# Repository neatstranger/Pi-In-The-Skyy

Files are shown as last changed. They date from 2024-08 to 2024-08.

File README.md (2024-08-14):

# Pi In The Skyy 

A PoE powered camera based on the Raspberry Pi Compute Module 4.
<br>

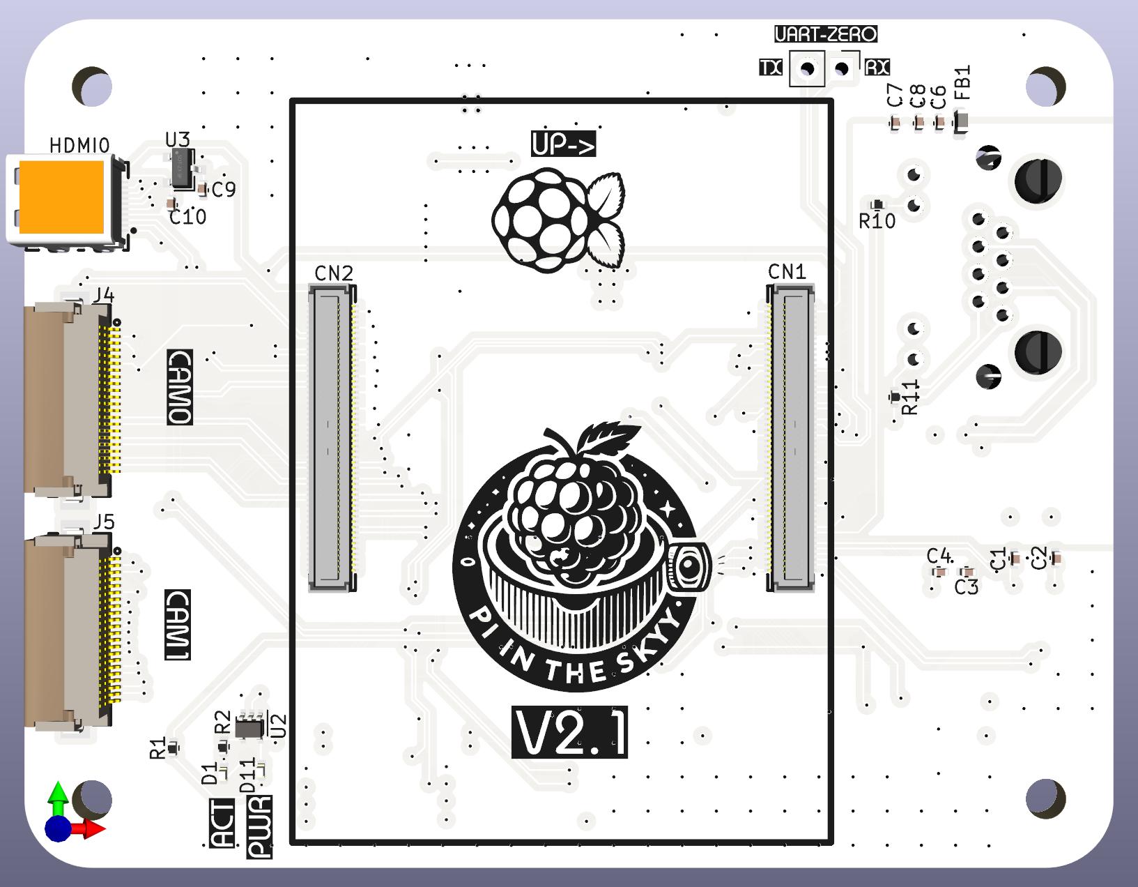
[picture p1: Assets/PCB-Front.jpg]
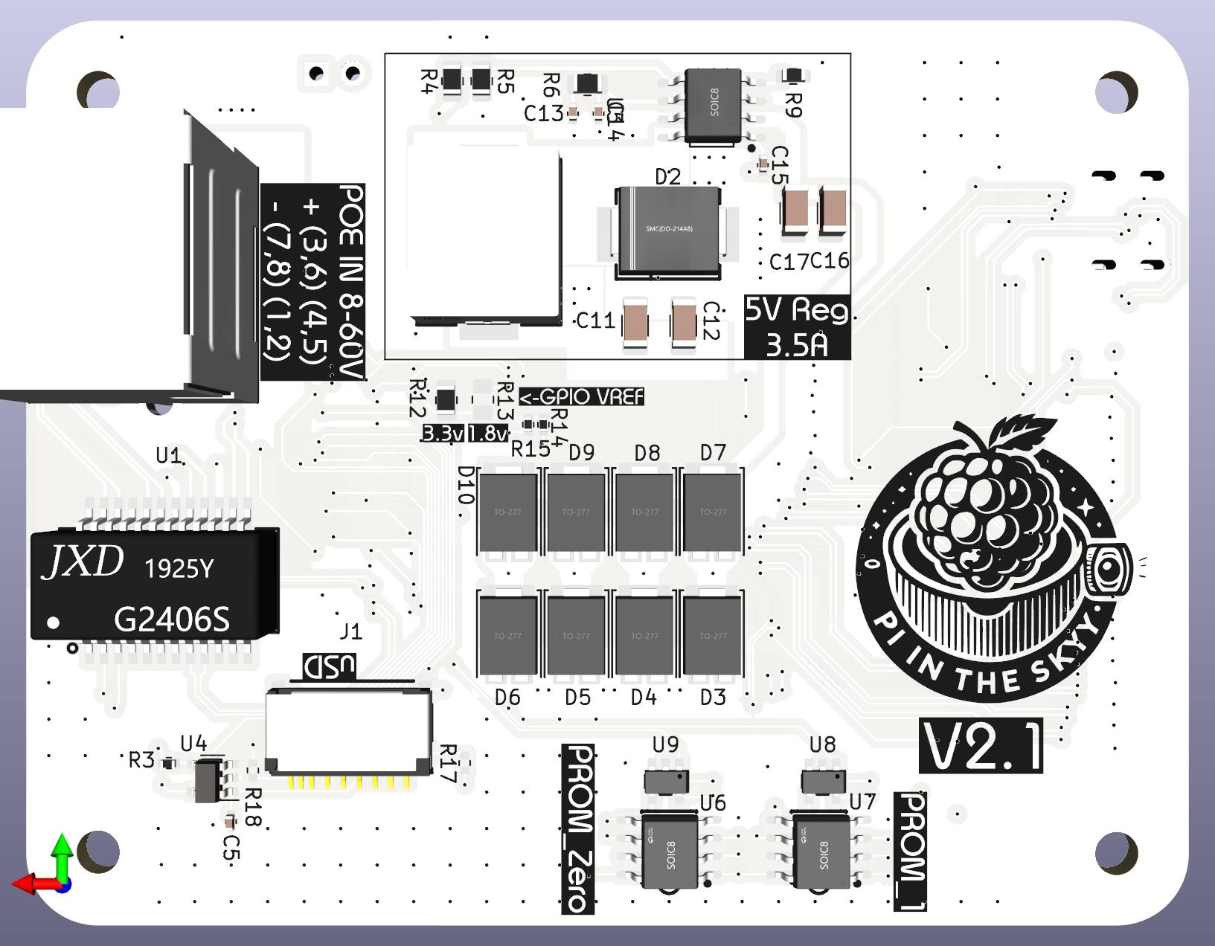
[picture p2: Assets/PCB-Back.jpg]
  

----

## Specs Overview
- Dual 22 Pin 0.5mm Pitch Camera Inputs
- Passive PoE In (8-60V)
- HDMI / UART Connectors For Troubleshooting
- Micro SD Card Slot

## Enclosure
The main body of the enclosure is designed to be 3D printed out of ASA, but PLA/PETG would work just as well. Acrylic dome found on Amazon.

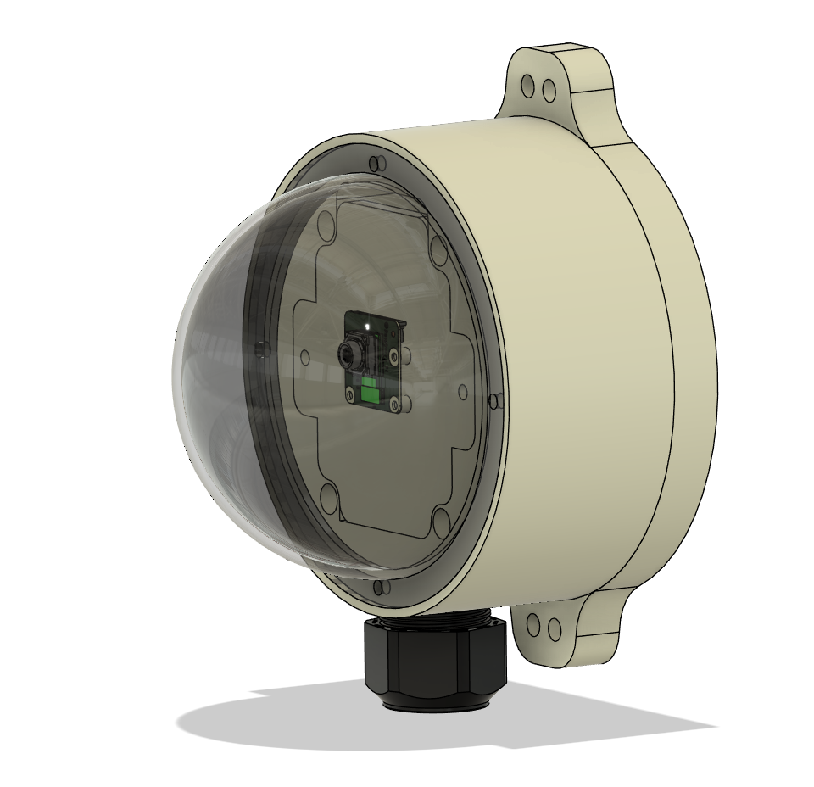
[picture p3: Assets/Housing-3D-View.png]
 

## Camera Mounting Hole Compatability
As far as I can tell, any of the first party v1, v2, and v3 cameras should work with the existing mounting plate. HQ/GS will need a new plate.

## Flexible Printed Circuit (FPC) Cable
You will need a 22 pin to 15 pin adapter cable. This is the same cable you would need to attach a first party camera to a RPi Zero, CM4IO board, or RPi5
[15 Way 1mm Spacing to 22 Way 0.5mm Spacing](https://www.pishop.us/product/camera-cable-for-raspberry-pi-5/)

## Power In
**Passive** POE IN 8-60V        Positive(3,6) (4,5)  Negative(7,8) (1,2) <br>
I have tons of passive PoE injectors from Ubiquiti equipment laying around, so I grabbed one like this:
[PoE+ Ubiquiti Injector](https://www.bhphotovideo.com/c/product/1737953-REG/ubiquiti_networks_u_poe_at_802_3at_supported_poe_injector.html/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)

All of the pairs don't have to exactly match, this one is +(4,5) , -(7,8). As long as you don't cross the expected negative and positive it should work just fine. Most PoE injectors on Amazon or otherwise will list the pinout in the description. 

Make sure you purchase one that is passive though. 
Active PoE requires components on the baord to negotiate power delivery. Which this carrier board doesn't have. We are just pulling the voltage from the center tap of the magnetics.

## Complete Part List
- [Raspberry Pi CM4](https://rpilocator.com/?cat=CM4)
- [v1, v2, v3 Camera Module](https://www.pishop.us/product/raspberry-pi-camera-module-3-wide/)
- [15 to 22 Pin Camera Cable](https://www.pishop.us/product/camera-cable-for-raspberry-pi-5/)
- Carrier Board has no source, but production files are ready to order from jlcpcb.com (Cost is ~$250 / 5 Boards)
- 3D Printed Case
- [100mm Acrylic Dome](https://www.amazon.com/dp/B07L6GLTNP?psc=1&ref=product_details)
- Various Fasteners and Heat Set Inserts. M3 for Most of Assembly, M2 For Camera Module
- [Gland For Cable Passthrough](https://www.mcmaster.com/5302N121/)

## Systemd Service for Streaming `/etc/systemd/system/camera-stream.service`
```
[Unit]
Description=open-source-nvr
Wants=network-online.target
After=network-online.target

[Service]
User=<user>
Group=<user>
Type=simple
ExecStart=/bin/sh /var/camstart.sh

[Install]
WantedBy=multi-user.target
```
^^^ Make sure to replace <user> with your login account.

## `/var/camstart.sh`
```
#!/bin/sh
rpicam-vid -t 0 --width 1920 --height 1080 --inline --nopreview --rotation 180 -o - | cvlc stream:///dev/stdin --sout '#rtp{sdp=rtsp://:8554/stream1}' :demux=h264

```

## After Creating both Files
```
sudo chmod +x /var/camstart.sh # make the service executable
sudo systemctl daemon-reload #reload the system file
sudo systemctl start camera-stream #start the camera stream
sudo systemctl enable camera-stream
```

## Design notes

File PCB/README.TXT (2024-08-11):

These files have been created in version 6 of KiCAD.

Some of the 3d models need to be downloaded form the following places and put into the CM4IO.3shapes directory some models are approximations.

https://datasheets.raspberrypi.org/cm4/CM4-step.zip
https://www.amphenol-icc.com/pci-express-1001878311200tlf.html
https://www.te.com/global-en/product-171826-4.html
https://www.molex.com/molex/products/part-detail/memory_card_socket/5033981892

The models provided in the 3dmodels directory are from various manufacturers including Diodes, Hirose, MTCONN,Toby, TRXCOM. Terms and conditions for the use of the models remain with the original manufacture.

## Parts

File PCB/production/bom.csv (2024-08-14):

Designator | Footprint | Quantity | Value | LCSC Part #
C1, C10, C2, C3, C4, C6, C7, C8, C9 | 0402 | 9 | 100n | C309458
C11, C12 | 1206 | 2 | 47u | C94034
C13 | 0402 | 1 | 6800p | C2760541
C14 | 0402 | 1 | 39p | C5186878
C15 | 0402 | 1 | 0.1u | C56392
C16, C17 | 1206 | 2 | 2.2u | C170101
C5 | 0402 | 1 | 10u | C315248
CN1, CN2 | CONN-SMD_DF40C-100DS-0.4V-51 | 2 | DF40C-100DS-0.4V(51) | C597931
D1 | 0402 | 1 | LED-RED | C434445
D10, D3, D4, D5, D6, D7, D8, D9 | TO-277A_L4.7-W6.1-LS6.6-TR | 8 | SB10100L | C113946
D11 | 0402 | 1 | LED-Green | C434446
D2 | SMC_L7.1-W6.2-LS8.1-RD | 1 | B560C-13-F | C85100
FB1 | 0603 | 1 | MPZ1608D101BTA00 | C87554
HDMI0 | HDMI-SMD_HDMI-101S | 1 | HDMI-101S | C720620
J1 | TF-SMD_TF-018 | 1 | Micro_SD_Card_Det | C961679
J4, J5 | FPC-SMD_22P-P0.50_FH12-22S-0.5SH-55 | 2 | Conn_01x22_Female | C597981
L2 | IND-SMD_L11.5-W10.0_FXL1040 | 1 | FXL1040-8R2-M | C167232
R1, R2 | 0402 | 2 | 1k | C11702
R10, R11 | 0402 | 2 | 470 | C25167
R12 | 0805 | 1 | 0R | C17477
R14, R15 | 0402 | 2 | 2.2k | C25879
R3 | 0402 | 1 | 12k | C102781
R4 | 0805 | 1 | 53.6k | C21398
R5 | 0805 | 1 | 10.2k | C217771
R6 | 0805 | 1 | 13k | C445658
R9 | 0603 | 1 | 162k | C22815
RJ2 | RJ45-TH_R-RJ45R08P-C000 | 1 | R-RJ45R08P-C000 | C386757
U1 | SMD-24_L15.1-W7.1-P1.00-LS10.0-BL | 1 | QG2439S | C3003223
U2 | SOT-353_SC-70-5 | 1 | 74LVC1G07SE-7 | C7464692
U3 | SOT-23-3_L2.9-W1.3-P1.90-LS2.4-BR | 1 | AP2331SA-7 | C500764
U4 | SOT-23-5 | 1 | RT9742GGJ5 | C250547
U5 | SOIC-8_L5.0-W4.0-P1.27-LS6.0-BL-EP2.0 | 1 | TPS54360BDDAR | C524806
U6, U7 | SOIC-8_L5.0-W4.0-P1.27-LS6.0-BL | 2 | M24C64-WMN6TP | C7999
U8, U9 | SOT-23-5_L2.9-W1.6-P0.95-LS2.8-BR | 2 | 74LVC1G125GV-TP | C3040595

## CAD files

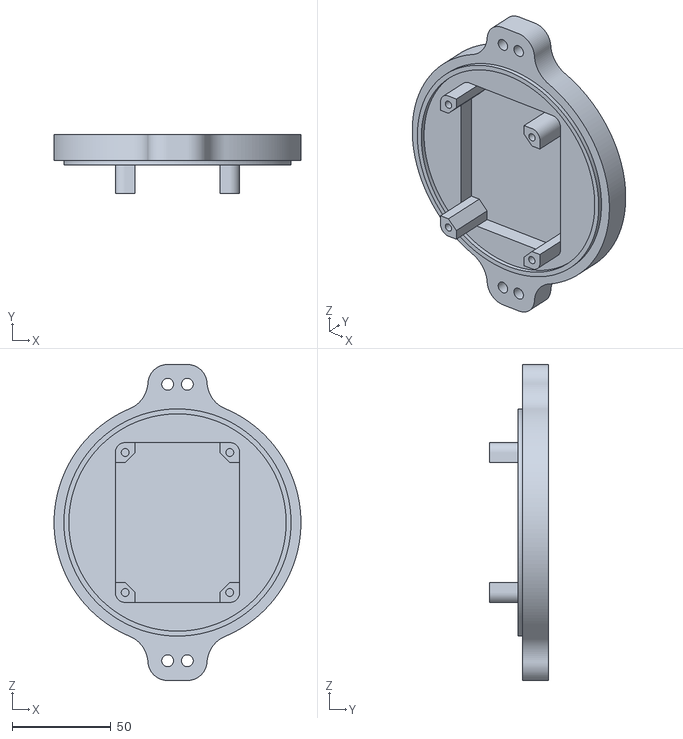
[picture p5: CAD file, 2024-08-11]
3D Files/STL/Bottom.stl
125.0 x 30.0 x 160.0

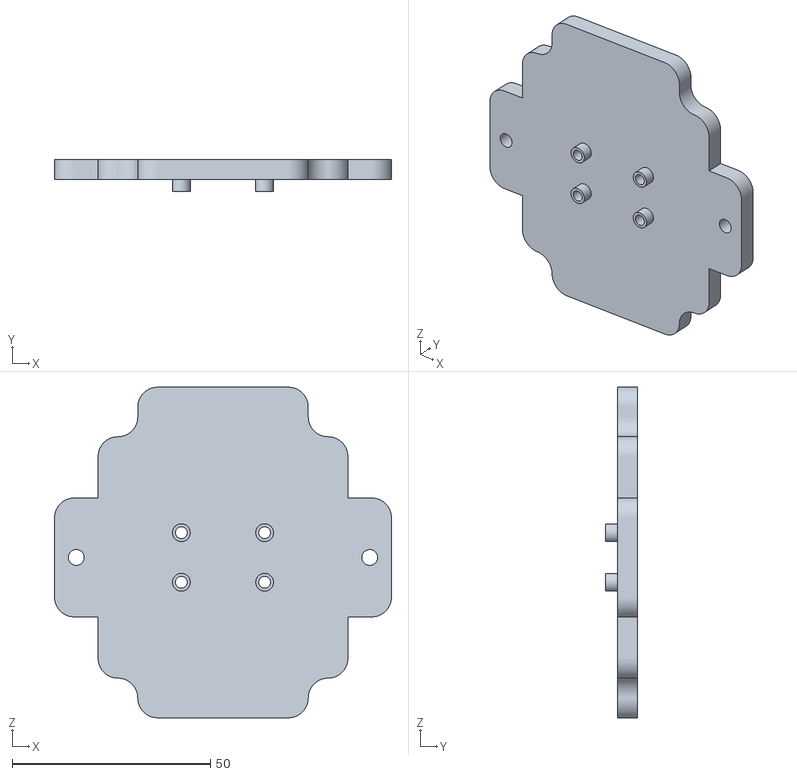
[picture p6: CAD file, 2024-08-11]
3D Files/STL/Camera Mount.stl
85.0 x 8.00 x 83.4

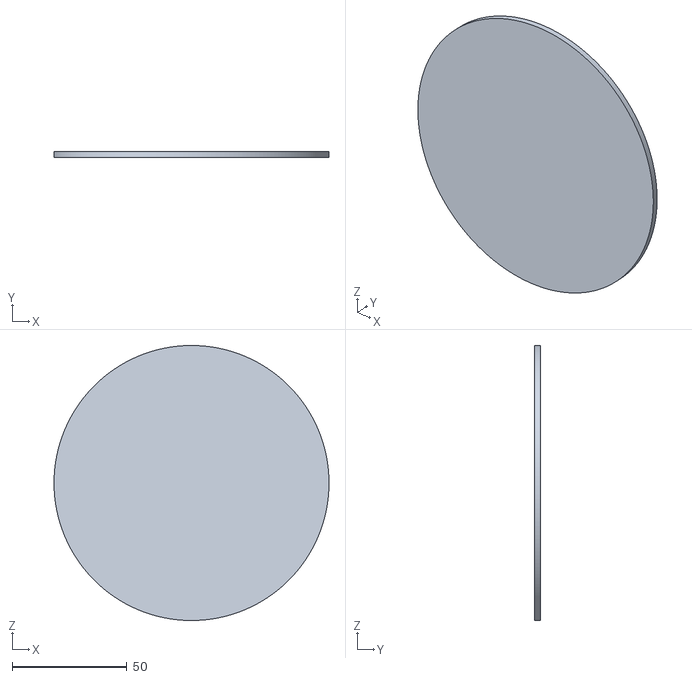
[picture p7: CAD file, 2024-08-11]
3D Files/STL/Enamel Protector.stl
120.0 x 2.50 x 120.0

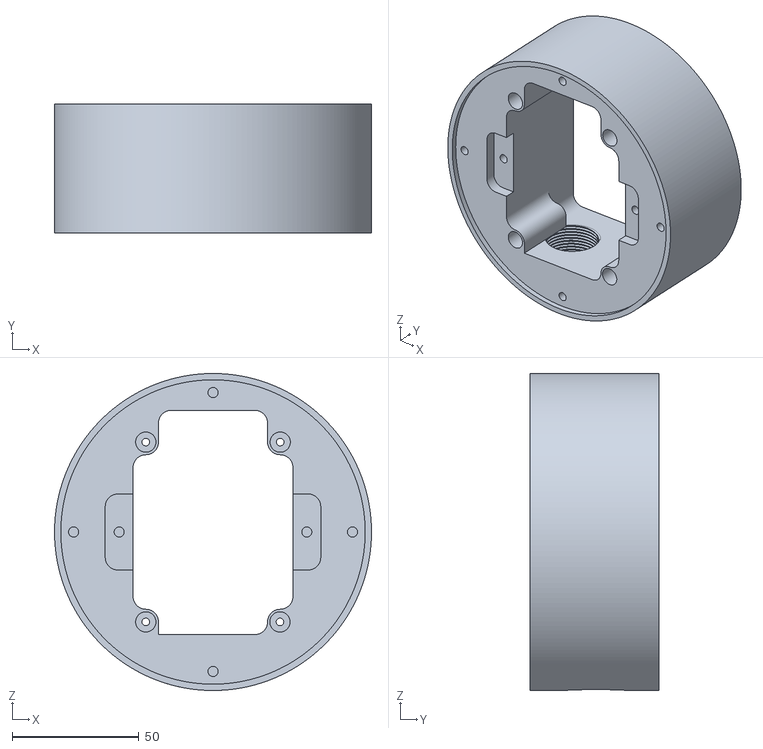
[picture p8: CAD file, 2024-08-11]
3D Files/STL/Dome Mount.stl
125.0 x 50.8 x 125.0

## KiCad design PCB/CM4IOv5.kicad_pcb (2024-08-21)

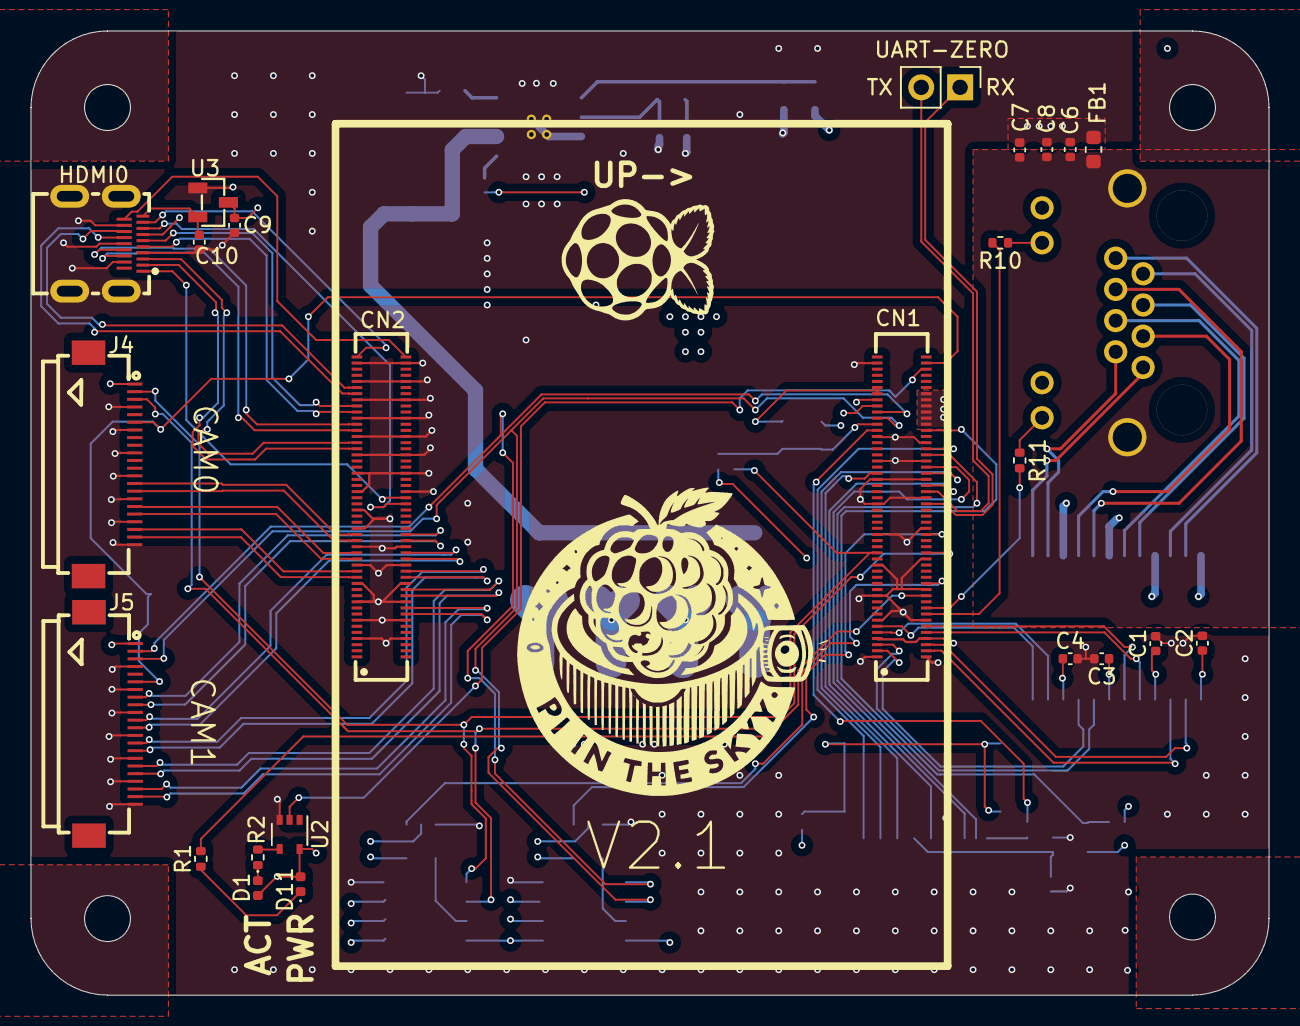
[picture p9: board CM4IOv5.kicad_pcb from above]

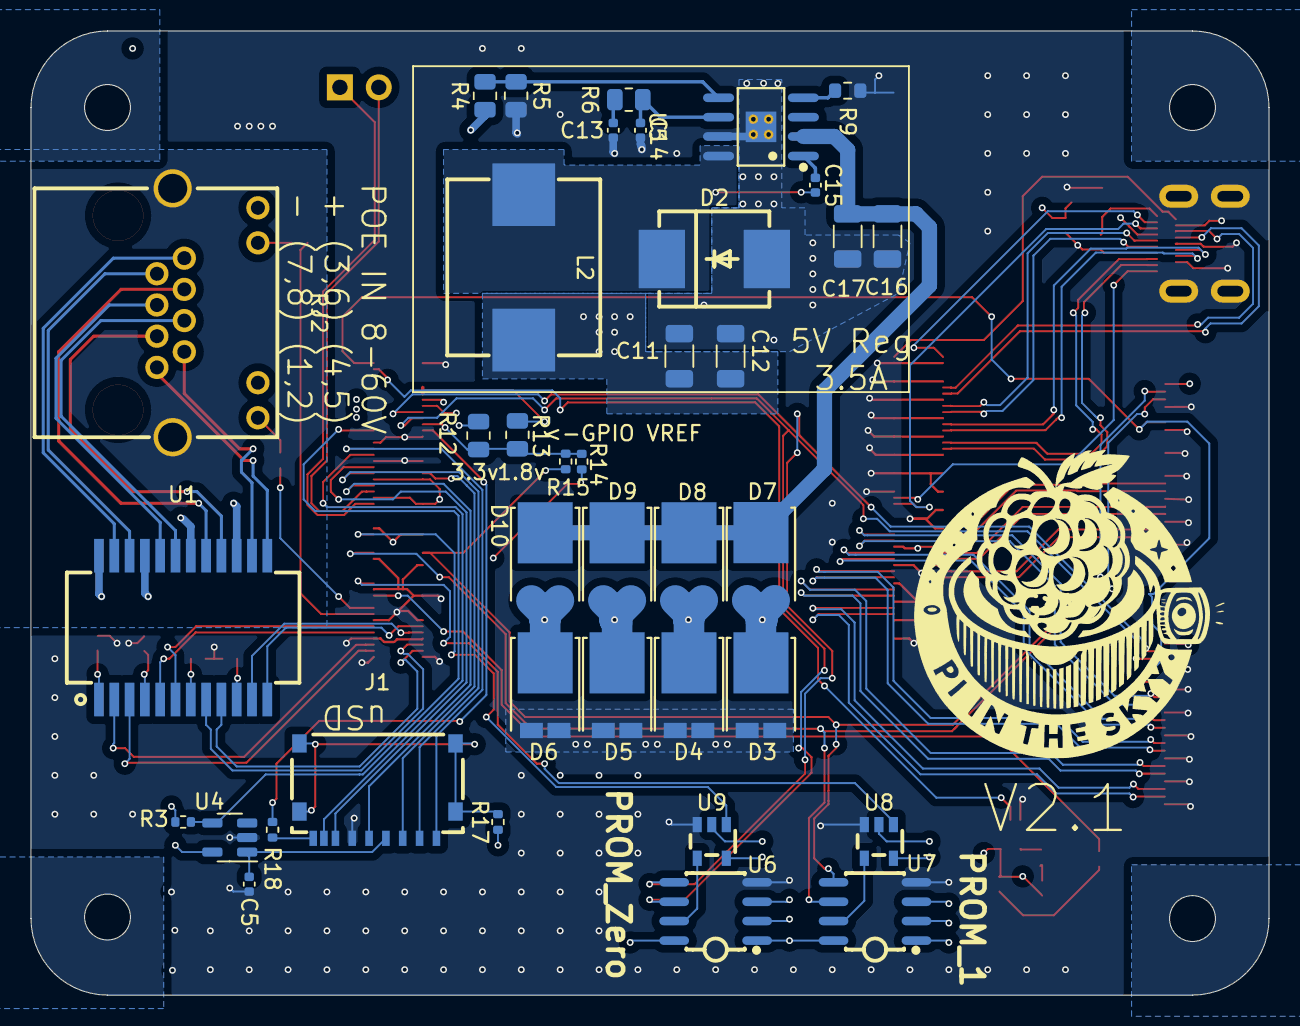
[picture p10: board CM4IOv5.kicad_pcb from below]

Board: 6 copper layers, 80.9 x 63.0 mm, 63 parts (38 on the bottom side), 97 nets.

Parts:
C1, C2, C3, C4, C6, C7, C8, C9, C10: 100n; C_0402_1005Metric
C5: 10u; C_0402_1005Metric
C11, C12: 47u; C_1206_3216Metric
C13: 6800p; C_0402_1005Metric
C14: 39p; C_0402_1005Metric
C15: 0.1u; C_0402_1005Metric
C16, C17: 2.2u; C_1206_3216Metric
CN1, CN2: DF40C-100DS-0.4V(51); CONN-SMD_DF40C-100DS-0.4V-51
D1: LED-RED; LED_0402_1005Metric
D2: B560C-13-F; SMC_L7.1-W6.2-LS8.1-RD
D3, D4, D5, D6, D7, D8, D9, D10: SB10100L; TO-277A_L4.7-W6.1-LS6.6-TR
D11: LED-Green; LED_0402_1005Metric
FB1: MPZ1608D101BTA00; L_0603_1608Metric
HDMI0: HDMI-101S; HDMI-SMD_HDMI-101S
J1: Micro_SD_Card_Det; TF-SMD_TF-018
J2: Conn_01x02_Pin; PinHeader_1x02_P2.54mm_Vertical
J4, J5: Conn_01x22_Female; FPC-SMD_22P-P0.50_FH12-22S-0.5SH-55
L2: FXL1040-8R2-M; IND-SMD_L11.5-W10.0_FXL1040
R1, R2: 1k; R_0402_1005Metric
R3: 12k; R_0402_1005Metric
R4: 53.6k; R_0805_2012Metric
R5: 10.2k; R_0805_2012Metric
R6: 13k; R_0805_2012Metric
R9: 162k; R_0603_1608Metric
R10, R11: 470; R_0402_1005Metric
R12: 0R; R_0805_2012Metric
R13: nf; R_0805_2012Metric
R14, R15: 2.2k; R_0402_1005Metric
R17, R18: nf; R_0402_1005Metric
RJ2: R-RJ45R08P-C000; RJ45-TH_R-RJ45R08P-C000
U1: QG2439S; SMD-24_L15.1-W7.1-P1.00-LS10.0-BL
U2: 74LVC1G07SE-7; SOT-353_SC-70-5
U3: AP2331SA-7; SOT-23-3_L2.9-W1.3-P1.90-LS2.4-BR
U4: RT9742GGJ5; SOT-23-5
U5: TPS54360BDDAR; SOIC-8_L5.0-W4.0-P1.27-LS6.0-BL-EP2.0
U6, U7: M24C64-WMN6TP; SOIC-8_L5.0-W4.0-P1.27-LS6.0-BL
U8, U9: 74LVC1G125GV-TP; SOT-23-5_L2.9-W1.6-P0.95-LS2.8-BR
UP->: LOGO

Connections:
/+3.3v: CN1.42, CN1.43, D1.2 (A), D11.2 (A), J4.1, J5.1, R3.1, R12.1, R17.1, RJ2.9 (L+), RJ2.11 (R+), U2.5 (VCC), U4.5 (IN), U6.1 (E0), U6.2 (E1), U6.3 (E2), U6.8 (VCC), U7.1 (E0), U7.2 (E1), U7.3 (E2), U7.8 (VCC), U8.2 (INA), U8.5 (VCC), U9.2 (INA), U9.5 (VCC)
/+5v: C9.1, C11.1, C12.1, CN1.57, CN1.58, CN1.59, CN1.60, CN1.61, CN1.62, L2.2, R4.1, U3.3 (IN)
/CM4_GPIO ( Ethernet, GPIO, SDCARD)/+1.8v: CN1.44, CN1.45, R13.1
/CM4_GPIO ( Ethernet, GPIO, SDCARD)/ActivityLED: CN1.90, R1.2
/CM4_GPIO ( Ethernet, GPIO, SDCARD)/BI_DA+: RJ2.1, U1.13
/CM4_GPIO ( Ethernet, GPIO, SDCARD)/BI_DA-: RJ2.2, U1.14
/CM4_GPIO ( Ethernet, GPIO, SDCARD)/BI_DB+: RJ2.3, U1.16
/CM4_GPIO ( Ethernet, GPIO, SDCARD)/BI_DB-: RJ2.6, U1.17
/CM4_GPIO ( Ethernet, GPIO, SDCARD)/BI_DC+: RJ2.4, U1.19
/CM4_GPIO ( Ethernet, GPIO, SDCARD)/BI_DC-: RJ2.5, U1.20
/CM4_GPIO ( Ethernet, GPIO, SDCARD)/BI_DD+: RJ2.7, U1.22
/CM4_GPIO ( Ethernet, GPIO, SDCARD)/BI_DD-: RJ2.8, U1.23
/CM4_GPIO ( Ethernet, GPIO, SDCARD)/ETH_LEDG: CN1.92, R11.2
/CM4_GPIO ( Ethernet, GPIO, SDCARD)/ETH_LEDY: CN1.93, R10.2
/CM4_GPIO ( Ethernet, GPIO, SDCARD)/GPIO14_UART0_TXD: CN1.73, J2.2
/CM4_GPIO ( Ethernet, GPIO, SDCARD)/GPIO15_UART0_RXD: CN1.75, J2.1
/CM4_GPIO ( Ethernet, GPIO, SDCARD)/GPIO21: CN1.88, U8.1 (~G)
/CM4_GPIO ( Ethernet, GPIO, SDCARD)/GPIO25: CN1.80, U9.1 (~G)
/CM4_GPIO ( Ethernet, GPIO, SDCARD)/GPIO_VREF: CN1.39, R12.2, R13.2, R14.2, R15.2
/CM4_GPIO ( Ethernet, GPIO, SDCARD)/ID_SC: CN1.83, J4.3, R14.1, U7.6 (SCL)
/CM4_GPIO ( Ethernet, GPIO, SDCARD)/ID_SD: CN1.18, J4.2, R15.1, U7.5 (SDA)
/CM4_GPIO ( Ethernet, GPIO, SDCARD)/POE_VDD+: C16.1, C17.1, D7.3, D8.3, D9.3, D10.3, U5.2 (VIN)
/CM4_GPIO ( Ethernet, GPIO, SDCARD)/PROM0_WC: U6.7 (~WC), U9.4 (OUTY)
/CM4_GPIO ( Ethernet, GPIO, SDCARD)/PROM1_WC: U7.7 (~WC), U8.4 (OUTY)
/CM4_GPIO ( Ethernet, GPIO, SDCARD)/PoE_IN_A+: D3.3, D7.1, D7.2, U1.21
/CM4_GPIO ( Ethernet, GPIO, SDCARD)/PoE_IN_A-: D4.3, D8.1, D8.2, U1.24
/CM4_GPIO ( Ethernet, GPIO, SDCARD)/PoE_IN_B+: D5.3, D9.1, D9.2, U1.18
/CM4_GPIO ( Ethernet, GPIO, SDCARD)/PoE_IN_B-: D6.3, D10.1, D10.2, U1.15
/CM4_GPIO ( Ethernet, GPIO, SDCARD)/Reserved: CN1.38, R18.1
/CM4_GPIO ( Ethernet, GPIO, SDCARD)/SD_CLK: CN1.72, J1.5 (CLK)
/CM4_GPIO ( Ethernet, GPIO, SDCARD)/SD_CMD: CN1.31, J1.3 (CMD)
/CM4_GPIO ( Ethernet, GPIO, SDCARD)/SD_DAT0: CN1.69, J1.7 (DAT0)
/CM4_GPIO ( Ethernet, GPIO, SDCARD)/SD_DAT1: CN1.67, J1.8 (DAT1)
/CM4_GPIO ( Ethernet, GPIO, SDCARD)/SD_DAT2: CN1.66, J1.1 (DAT2)
/CM4_GPIO ( Ethernet, GPIO, SDCARD)/SD_DAT3: CN1.70, J1.2 (DAT3/CD)
/CM4_GPIO ( Ethernet, GPIO, SDCARD)/SD_PWR: C5.1, J1.4 (VDD), U4.1 (OUT)
/CM4_GPIO ( Ethernet, GPIO, SDCARD)/SD_PWR_ON: CN1.63, R3.2, U4.4 (EN)
/CM4_GPIO ( Ethernet, GPIO, SDCARD)/TRD0_N: CN1.5, U1.11
/CM4_GPIO ( Ethernet, GPIO, SDCARD)/TRD0_P: CN1.6, U1.12
/CM4_GPIO ( Ethernet, GPIO, SDCARD)/TRD1_N: CN1.3, U1.8
/CM4_GPIO ( Ethernet, GPIO, SDCARD)/TRD1_P: CN1.2, U1.9
/CM4_GPIO ( Ethernet, GPIO, SDCARD)/TRD2_N: CN1.96, U1.5
/CM4_GPIO ( Ethernet, GPIO, SDCARD)/TRD2_P: CN1.95, U1.6
/CM4_GPIO ( Ethernet, GPIO, SDCARD)/TRD3_N: CN1.98, U1.2
/CM4_GPIO ( Ethernet, GPIO, SDCARD)/TRD3_P: CN1.99, U1.3
/CM4_GPIO ( Ethernet, GPIO, SDCARD)/nPWR_LED: CN1.53, U2.2
/CM4_HighSpeed/CAM0_C_N: CN2.20, J4.15
/CM4_HighSpeed/CAM0_C_P: CN2.21, J4.14
/CM4_HighSpeed/CAM0_D0_N: CN2.14, J4.21
/CM4_HighSpeed/CAM0_D0_P: CN2.15, J4.20
/CM4_HighSpeed/CAM0_D1_N: CN2.17, J4.18
/CM4_HighSpeed/CAM0_D1_P: CN2.18, J4.17
/CM4_HighSpeed/CAM1_C_N: CN2.87, J5.15
/CM4_HighSpeed/CAM1_C_P: CN2.86, J5.14
/CM4_HighSpeed/CAM1_D0_N: CN2.93, J5.21
/CM4_HighSpeed/CAM1_D0_P: CN2.92, J5.20
/CM4_HighSpeed/CAM1_D1_N: CN2.90, J5.18
/CM4_HighSpeed/CAM1_D1_P: CN2.89, J5.17
/CM4_HighSpeed/CAM1_D2_N: CN2.84, J5.12
/CM4_HighSpeed/CAM1_D2_P: CN2.83, J5.11
/CM4_HighSpeed/CAM1_D3_N: CN2.81, J5.9
/CM4_HighSpeed/CAM1_D3_P: CN2.80, J5.8
/CM4_HighSpeed/CAM_GPIO: CN1.52, J4.6, J5.6
/CM4_HighSpeed/HDMI0_CEC: CN2.75, HDMI0.15 (CEC)
/CM4_HighSpeed/HDMI0_CK_N: CN2.45, HDMI0.14 (TMDS_CLOCK-)
/CM4_HighSpeed/HDMI0_CK_P: CN2.44, HDMI0.12 (TMDS_CLOCK+)
/CM4_HighSpeed/HDMI0_D0_N: CN2.42, HDMI0.11 (TMDS_DATA0-)
/CM4_HighSpeed/HDMI0_D0_P: CN2.41, HDMI0.9 (TMDS_DATA0+)
/CM4_HighSpeed/HDMI0_D1_N: CN2.39, HDMI0.8 (TMDS_DATA1-)
/CM4_HighSpeed/HDMI0_D1_P: CN2.38, HDMI0.6 (TMDS_DATA1+)
/CM4_HighSpeed/HDMI0_D2_N: CN2.36, HDMI0.5 (TMDS_DATA2-)
/CM4_HighSpeed/HDMI0_D2_P: CN2.35, HDMI0.3 (TMDS_DATA2+)
/CM4_HighSpeed/HDMI0_HOTPLUG: CN2.74, HDMI0.1 (HOT_PLUG_DET)
/CM4_HighSpeed/HDMI0_SCL: CN2.50, HDMI0.17 (SCL)
/CM4_HighSpeed/HDMI0_SDA: CN2.51, HDMI0.18 (SDA)
/CM4_HighSpeed/HDMI_5v: C10.1, HDMI0.19 (+5V), U3.2 (OUT)
/CM4_HighSpeed/SCL0: CN1.40, J5.3, U6.6 (SCL)
/CM4_HighSpeed/SDA0: CN1.41, J5.2, U6.5 (SDA)
/PSUS/FB: R4.2, R5.1, U5.5 (FB)
ENET_GND: C6.2, C7.2, C8.2, FB1.1, RJ2.13 (S), RJ2.14 (S)
GND: C1.2, C2.2, C3.2, C4.2, C5.2, C6.1, C7.1, C8.1, C9.2, C10.2, C11.2, C12.2, C13.2, C14.2, C16.2, C17.2, CN1.1, CN1.4, CN1.7, CN1.11, CN1.16, CN1.21, CN1.26, CN1.30, CN1.33, CN1.37, CN1.49, CN1.65, CN1.68, CN1.71, CN1.74, CN1.79, CN1.84, CN1.89, CN1.94, CN1.97, CN1.100, CN2.4, CN2.7, CN2.10, CN2.13, CN2.16, CN2.19, CN2.22, CN2.25, CN2.28, CN2.31, CN2.34, CN2.37, CN2.40, CN2.43, CN2.46, CN2.49, CN2.52, CN2.55, CN2.58, CN2.61, CN2.64, CN2.67, CN2.70, CN2.73, CN2.82, CN2.85, CN2.88, CN2.91, CN2.94, CN2.97, D2.2 (A), D3.1, D3.2, D4.1, D4.2, D5.1, D5.2, D6.1, D6.2, FB1.2, HDMI0.4 (TMDS_DATA2_SHIELD), HDMI0.7 (TMDS_DATA1_SHIELD), HDMI0.10 (TMDS_DATA0_SHIELD), HDMI0.13 (TMDS_CLOCK_SHIELD), HDMI0.16 (DDC/CEC_GND), HDMI0.20 (SHIELD), J1.6 (VSS), J4.4, J4.7, J4.10, J4.13, J4.16, J4.19, J4.22, J5.4, J5.7, J5.10, J5.13, J5.16, J5.19, J5.22, R5.2, R9.2, U2.3 (GND), U3.1 (GND), U4.2 (GND), U5.7 (GND), U5.9 (PAD), U6.4 (VSS), U7.4 (VSS), U8.3 (GND), U9.3 (GND)
unnamed: C1.1, U1.4
unnamed: C2.1, U1.1
unnamed: C3.1, U1.7
unnamed: C4.1, U1.10
unnamed: C13.1, R6.2
unnamed: D1.1 (K), R2.1
unnamed: C15.2, D2.1 (K), L2.1, U5.8 (SW)
unnamed: D11.1 (K), R1.1
unnamed: J1.10 (DET_A), R17.2
unnamed: J1.9 (DET_B), R18.2
unnamed: R2.2, U2.4
unnamed: R10.1, RJ2.10 (L-)
unnamed: R11.1, RJ2.12 (R-)
unnamed: C15.1, U5.1 (BOOT)
unnamed: C14.1, R6.1, U5.6 (COMP)
unnamed: R9.1, U5.4 (RT/CLK)

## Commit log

2024-08-11 First push
    [Bottom.stl, CM4IOv5.kicad_pcb, CM4IOv5.kicad_sch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]
2024-08-14 Added Primary and Secondary EEPROM
    This will be used to store configuration separate from the OS.
    [CM4_GPIO.kicad_sch]
2024-08-14 Had to go with an inverting buffer, to correctly setup the EEPROM
    The WC pin of the eeprom, disables writing when it is high. Default state has GPIO 25, and GPIO21 are pulled low.
    I want the EEPROM to disable writing until I am ready to write to it.
    During normal Pi Operation (GPIOlow) the eeprom is in the following state:
    Input A(+3.3V) = HIGH
    INPUT /G (GPIO) = LOW
    Output Y = LOW
    And when GPIO goes high, it is left floating, so writing can happen.
    Input A(+3.3V) = HIGH
    INPUT /G (GPIO) = HIGH
    Output Y = FLOAT
    [CM4_GPIO.kicad_sch]
2024-08-14 Routed EEPROM modules to SDA/SCL and GPIO pins.
    These are definitely taking up more space than they need to, but a little extra space will provide easier in-situ changes if rewiring is needed.
    [CM4IOv5.kicad_pcb]
2024-08-14 Updated fonts for export.
    [CM4IOv5.kicad_pcb]
2024-08-14 Updated silkscreen for release.
    Exported STEP/JLC Production Files.
    [CM4IOv5.kicad_pcb, bom.csv, designators.csv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]
2024-08-21 Fixed hole connected to every plain.
    [CM4IOv5.kicad_pcb]
2024-08-21 Moved silk screen to not clip.
    [CM4IOv5.kicad_pcb]

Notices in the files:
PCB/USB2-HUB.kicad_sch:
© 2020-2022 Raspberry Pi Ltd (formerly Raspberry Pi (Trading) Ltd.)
